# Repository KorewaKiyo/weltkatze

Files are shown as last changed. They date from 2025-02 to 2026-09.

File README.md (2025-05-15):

## A full hardware replacement for a small battery powered nightlight, which includes a bottom case, PCB + Zigbee microcontroller
Inspired by Blinkekatze

## Why?
It sounded like a fun challenge!

# More to come as the project progresses 
I've got boards but am waiting on some replacement components because I fried a couple MCUs while soldering :)

### Board view
animation

rendered with [kicad-render](https://github.com/linalinn/kicad-render)

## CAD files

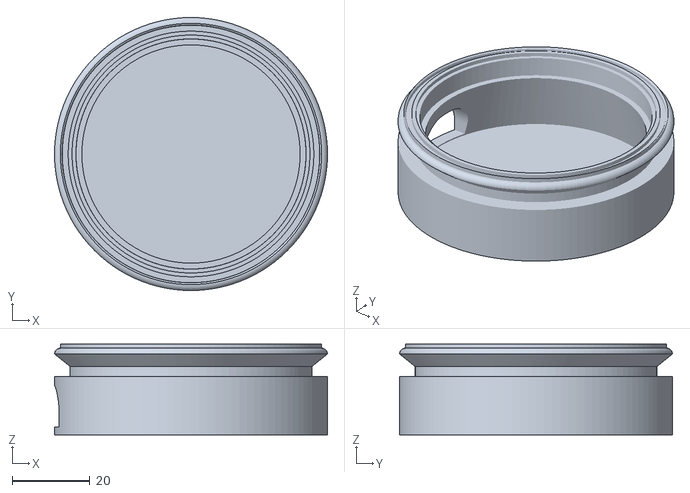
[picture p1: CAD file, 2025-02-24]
case/weltkatze_base.stl
70.0 x 70.0 x 23.2

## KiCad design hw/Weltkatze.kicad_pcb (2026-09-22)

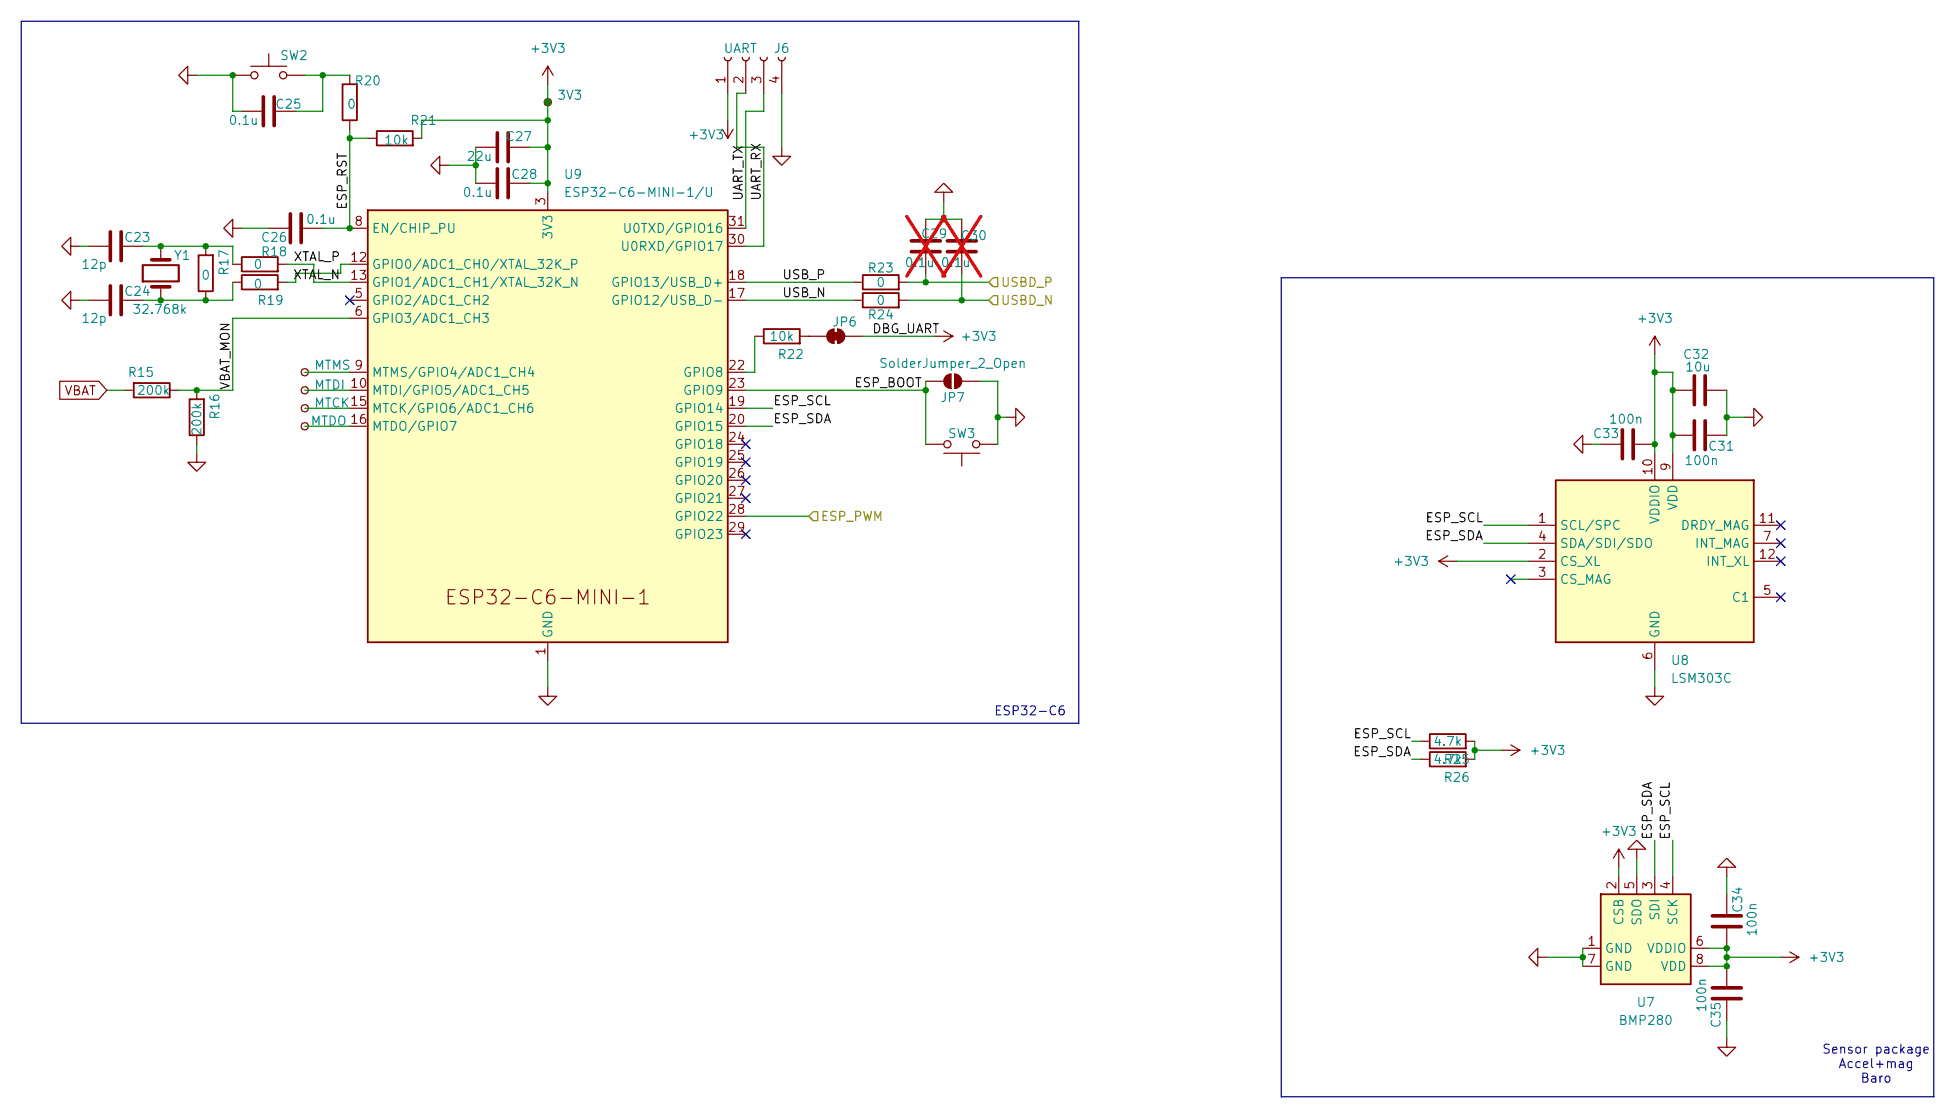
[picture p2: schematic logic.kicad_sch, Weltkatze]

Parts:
C23, C24: 12p; C_0402_1005Metric
C25, C26, C28: 0.1u; C_0402_1005Metric
C27: 22u; C_0805_2012Metric
C29, C30: 0.1u; C_0603_1608Metric; not fitted
C31, C33, C34, C35: 100n; C_0402_1005Metric
C32: 10u; C_0603_1608Metric
J6: UART; JST_ZH_B4B-ZR_1x04_P1.50mm_Vertical
JP6: DBG_UART; SolderJumper-2_P1.3mm_Bridged_Pad1.0x1.5mm
JP7: SolderJumper_2_Open; SolderJumper-2_P1.3mm_Open_TrianglePad1.0x1.5mm
R15, R16: 200k; R_0603_1608Metric
R17, R18, R19, R20, R23, R24: 0; R_0603_1608Metric
R21, R22: 10k; R_0603_1608Metric
R25, R26: 4.7k; R_0603_1608Metric
SW2, SW3: SW_Push; SW_SPST_CK_RS282G05A3
TP1: MTMS; TestPoint_Pad_D1.0mm
TP2: MTDI; TestPoint_Pad_D1.0mm
TP3: MTCK; TestPoint_Pad_D1.0mm
TP4: MTDO; TestPoint_Pad_D1.0mm
TP5: 3V3; TestPoint_Pad_D1.0mm
U7: BMP280; Bosch_LGA-8_2x2.5mm_P0.65mm_ClockwisePinNumbering
U8: LSM303C; LGA-12_2x2mm_P0.5mm
U9: ESP32-C6-MINI-1/U; ESP32-C6-MINI-1
Y1: 32.768k; Crystal_C26-LF_D2.1mm_L6.5mm_Horizontal

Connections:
+3V3: C27.2, C28.2, C31.1, C32.1, C33.1, C34.1, C35.1, J6.1, JP6.2 (B), R21.2, R25.2, R26.2, TP5.1, U7.2 (CSB), U7.6 (VDDIO), U7.8 (VDD), U8.2 (CS_XL), U8.9 (VDD), U8.10 (VDDIO), U9.3 (3V3); also elsewhere on the board
/LEDs/LED_DIN: U9.28 (GPIO22); also elsewhere on the board
/Logic/ESP_BOOT: JP7.1 (A), SW3.2, U9.23 (GPIO9)
/Logic/ESP_RST: C26.1, R20.1, R21.1, U9.8 (EN/CHIP_PU)
/Logic/ESP_SCL: R25.1, U7.4 (SCK), U8.1 (SCL/SPC), U9.19 (GPIO14)
/Logic/ESP_SDA: R26.1, U7.3 (SDI), U8.4 (SDA/SDI/SDO), U9.20 (GPIO15)
/Logic/UART_RX: J6.2, U9.30 (U0RXD/GPIO17)
/Logic/UART_TX: J6.3, U9.31 (U0TXD/GPIO16)
/Logic/USBD_N: C30.2, R24.2; also elsewhere on the board
/Logic/USBD_P: C29.2, R23.2; also elsewhere on the board
/Logic/USB_N: R24.1, U9.17 (GPIO12/USB_D-)
/Logic/USB_P: R23.1, U9.18 (GPIO13/USB_D+)
/Logic/VBAT_MON: R15.1, R16.2, U9.6 (GPIO3/ADC1_CH3)
/Logic/XTAL_N: R18.2, U9.13 (GPIO1/ADC1_CH1/XTAL_32K_N)
/Logic/XTAL_P: R19.2, U9.12 (GPIO0/ADC1_CH0/XTAL_32K_P)
GND: C23.1, C24.1, C25.1, C26.2, C27.1, C28.1, C29.1, C30.1, C31.2, C32.2, C33.2, C34.2, C35.2, J6.4, JP7.2 (B), R16.1, SW2.1, SW3.1, U7.1 (GND), U7.5 (SDO), U7.7 (GND), U8.6 (GND), U8.8 (GND), U9.1 (GND), U9.2 (GND), U9.11 (GND), U9.14 (GND), U9.36 (GND), U9.37 (GND), U9.38 (GND), U9.39 (GND), U9.40 (GND), U9.41 (GND), U9.42 (GND), U9.43 (GND), U9.44 (GND), U9.45 (GND), U9.46 (GND), U9.47 (GND), U9.48 (GND), U9.49 (GND), U9.50 (GND), U9.51 (GND), U9.52 (GND), U9.53 (GND); also elsewhere on the board
unnamed: C23.2, R17.2, R18.1, Y1.2
unnamed: C24.2, R17.1, R19.1, Y1.1
unnamed: C25.2, R20.2, SW2.2
unnamed: JP6.1 (A), R22.2
unnamed: R22.1, U9.22 (GPIO8)
unnamed: TP3.1, U9.15 (MTCK/GPIO6/ADC1_CH6)
unnamed: TP2.1, U9.10 (MTDI/GPIO5/ADC1_CH5)
unnamed: TP4.1, U9.16 (MTDO/GPIO7)
unnamed: TP1.1, U9.9 (MTMS/GPIO4/ADC1_CH4)
VBAT: R15.2; also elsewhere on the board

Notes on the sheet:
Sensor package Accel+mag Baro
ESP32-C6

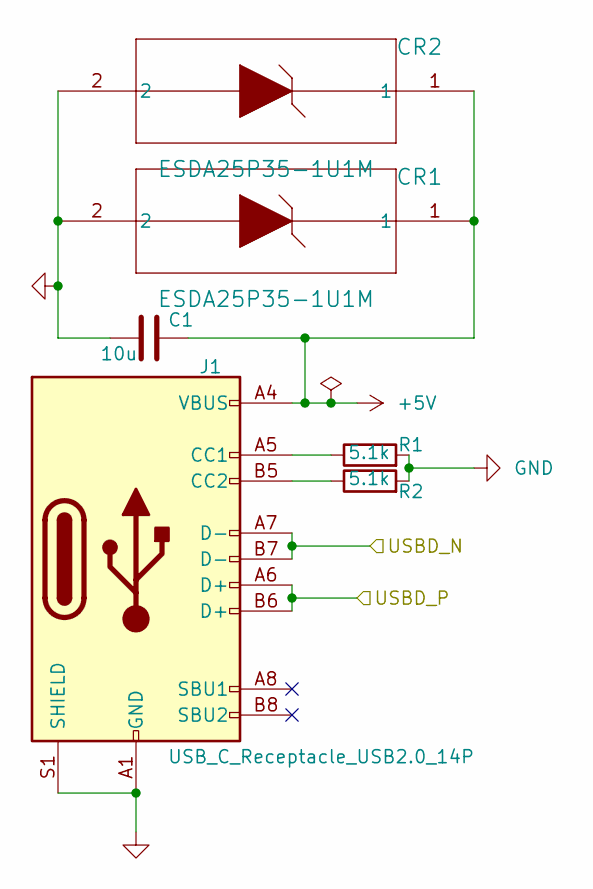
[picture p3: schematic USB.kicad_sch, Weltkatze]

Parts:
C1: 10u; C_0603_1608Metric
CR1, CR2: ESDA25P35-1U1M; QFN1610_STM-M
J1: USB_C_Receptacle_USB2.0_14P; USB_C_Receptacle_HCTL_HC-TYPE-C-16P-01A
R1, R2: 5.1k; R_0603_1608Metric

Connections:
+5V: C1.1, CR1.1, CR2.1, J1.A4 (VBUS), J1.A9 (VBUS), J1.B4 (VBUS), J1.B9 (VBUS); also elsewhere on the board
/Logic/USBD_N: J1.A7 (D-), J1.B7 (D-); also elsewhere on the board
/Logic/USBD_P: J1.A6 (D+), J1.B6 (D+); also elsewhere on the board
GND: C1.2, CR1.2, CR2.2, J1.A1 (GND), J1.A12 (GND), J1.B1 (GND), J1.B12 (GND), J1.S1 (SHIELD), R1.2, R2.2; also elsewhere on the board
unnamed: J1.A5 (CC1), R1.1
unnamed: J1.B5 (CC2), R2.1

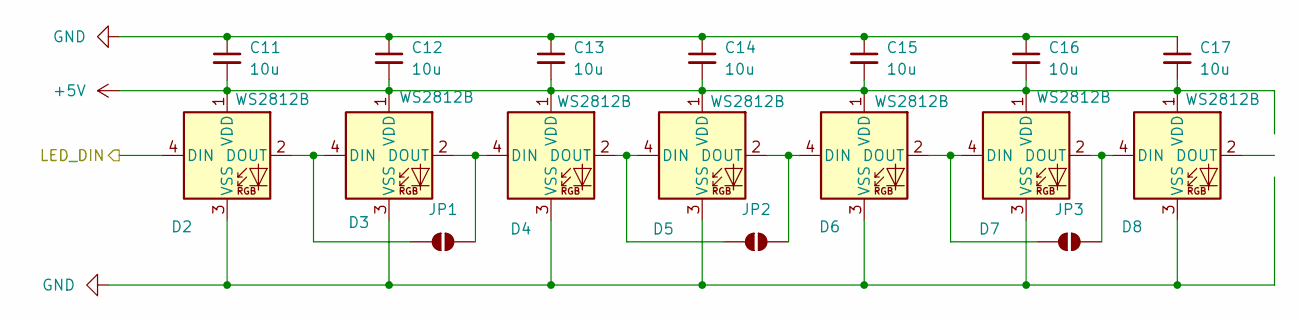
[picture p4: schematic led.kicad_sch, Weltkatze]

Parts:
C11, C12, C13, C14, C15, C16, C17: 10u; C_0603_1608Metric
D2, D3, D4, D5, D6, D7, D8: WS2812B; LED_WS2812B_PLCC4_5.0x5.0mm_P3.2mm
JP1, JP2, JP3: SolderJumper_2_Open; SolderJumper-2_P1.3mm_Open_TrianglePad1.0x1.5mm

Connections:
+5V: C11.2, C12.2, C13.2, C14.2, C15.2, C16.2, C17.2, D2.1 (VDD), D3.1 (VDD), D4.1 (VDD), D5.1 (VDD), D6.1 (VDD), D7.1 (VDD), D8.1 (VDD); also elsewhere on the board
/LEDs/LED_DIN: D2.4 (DIN); also elsewhere on the board
GND: C11.1, C12.1, C13.1, C14.1, C15.1, C16.1, C17.1, D2.3 (VSS), D3.3 (VSS), D4.3 (VSS), D5.3 (VSS), D6.3 (VSS), D7.3 (VSS), D8.3 (VSS); also elsewhere on the board
unnamed: D2.2 (DOUT), D3.4 (DIN), JP1.1 (A)
unnamed: D3.2 (DOUT), D4.4 (DIN), JP1.2 (B)
unnamed: D4.2 (DOUT), D5.4 (DIN), JP2.1 (A)
unnamed: D5.2 (DOUT), D6.4 (DIN), JP2.2 (B)
unnamed: D6.2 (DOUT), D7.4 (DIN), JP3.1 (A)
unnamed: D7.2 (DOUT), D8.4 (DIN), JP3.2 (B)

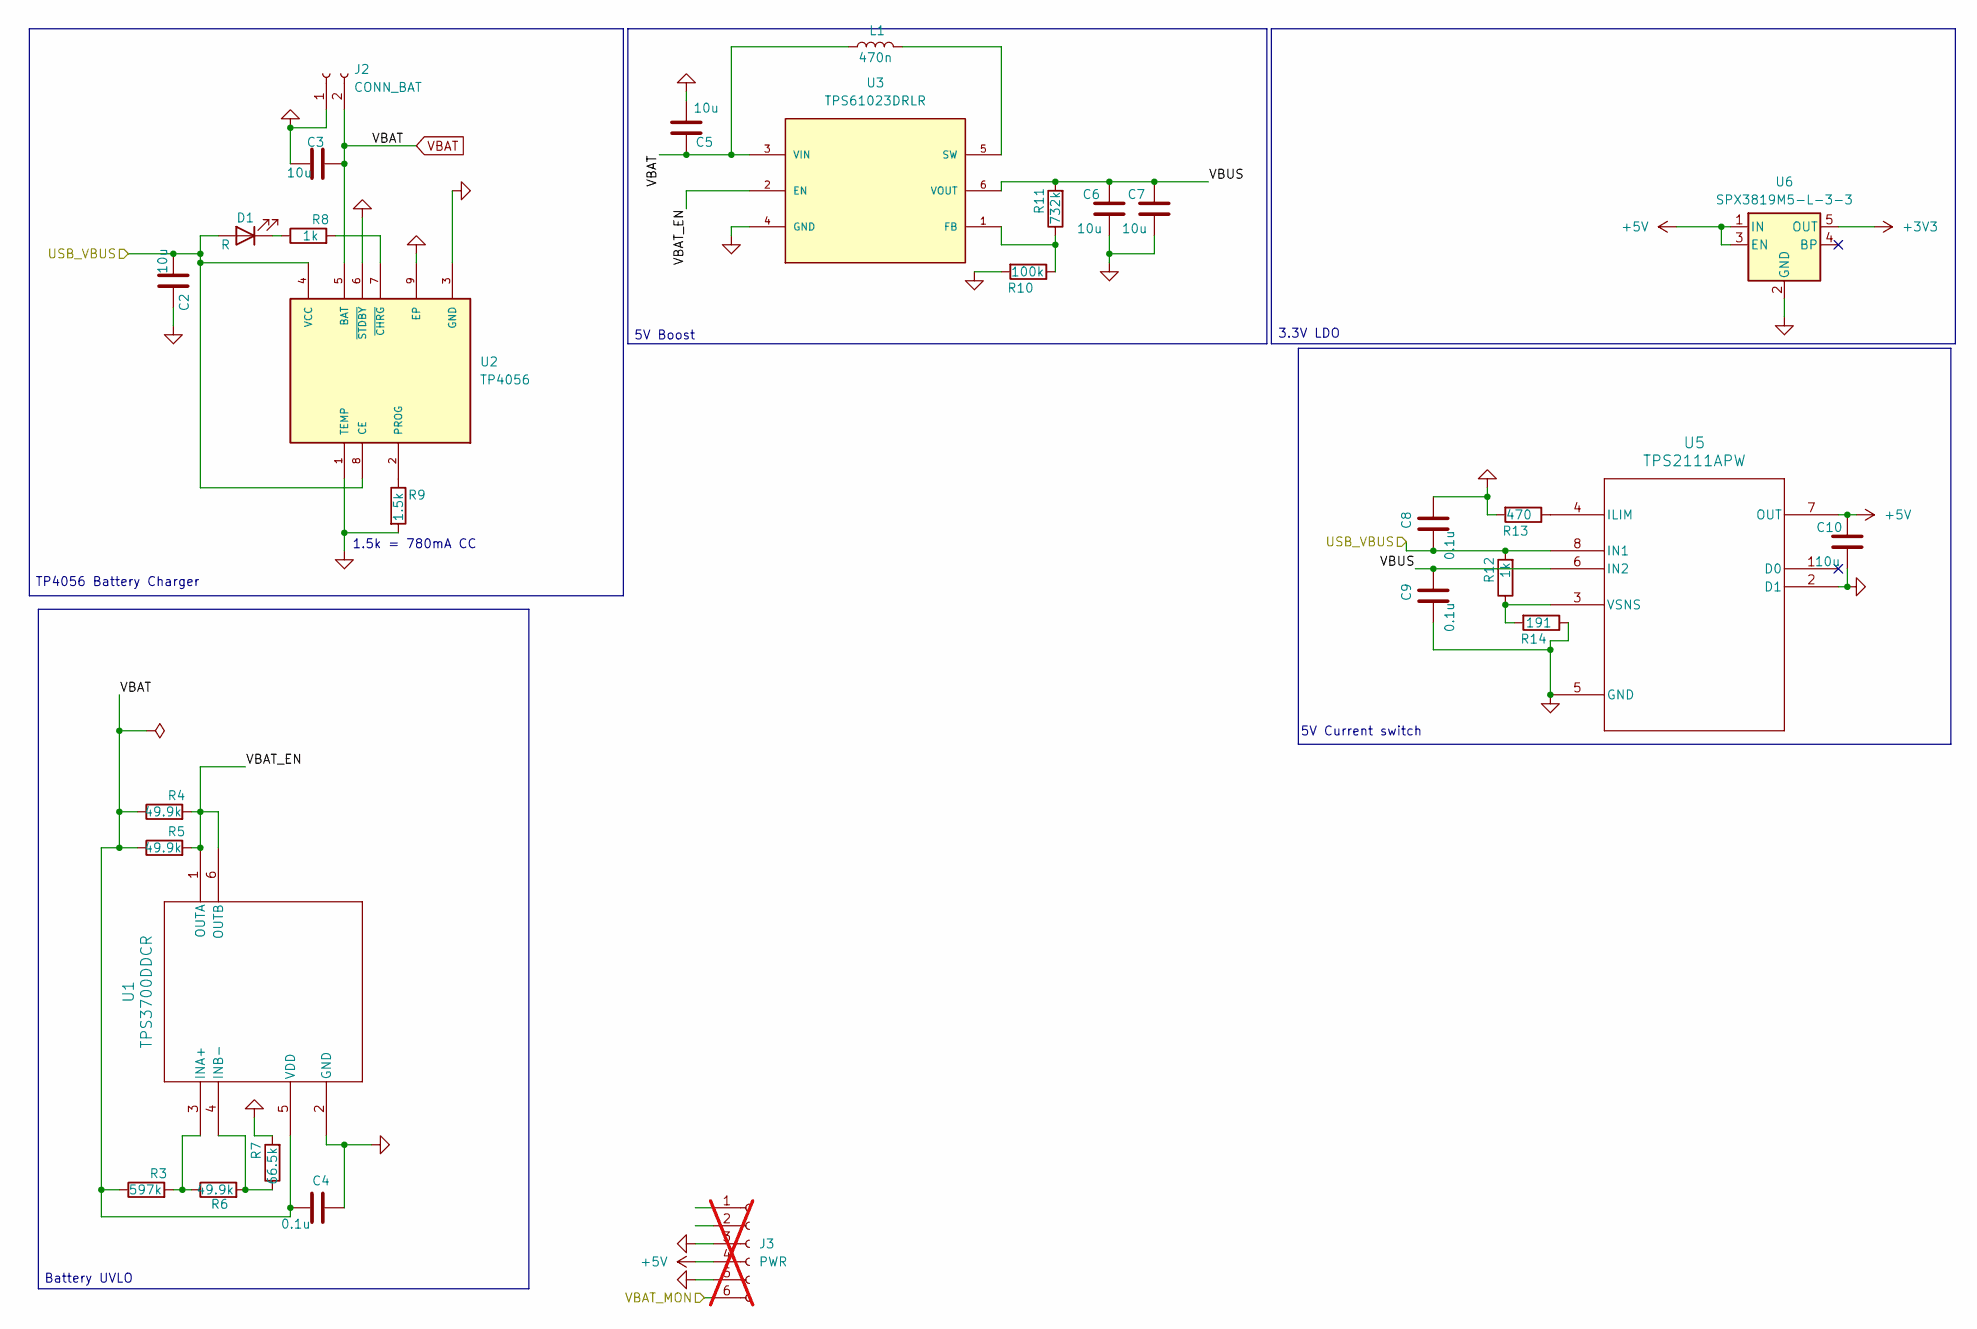
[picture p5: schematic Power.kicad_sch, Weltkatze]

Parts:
C2, C3, C5, C6, C7, C10: 10u; C_0603_1608Metric
C4, C8, C9: 0.1u; C_0402_1005Metric
D1: R; LED_0603_1608Metric
J2: CONN_BAT; JST_XH_B2B-XH-A_1x02_P2.50mm_Vertical
J3: PWR; JST_ZH_B6B-ZR_1x06_P1.50mm_Vertical; not fitted
L1: 470n; L_0805_2012Metric
R3: 597k; R_0603_1608Metric
R4, R5, R6: 49.9k; R_0603_1608Metric
R7: 66.5k; R_0603_1608Metric
R8, R12: 1k; R_0603_1608Metric
R9: 1.5k; R_0603_1608Metric
R10: 100k; R_0603_1608Metric
R11: 732k; R_0603_1608Metric
R13: 470; R_0603_1608Metric
R14: 191; R_0603_1608Metric
U1: TPS3700DDCR; DDC6_TEX-M
U2: TP4056; SOP127P600X175-9N
U3: TPS61023DRLR; DRL0006A; MANUFACTURER_PART_NUMBER TPS61023DRLR
U5: TPS2111APW; PW8
U6: SPX3819M5-L-3-3; SOT-23-5

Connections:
+3V3: U6.5 (OUT); also elsewhere on the board
+5V: C10.1, J3.4, U5.7 (OUT), U6.1 (IN), U6.3 (EN); also elsewhere on the board
/Power/USB_VBUS: C2.1, C8.1, D1.2 (A), R12.2, U2.4 (VCC), U2.8 (CE), U5.8 (IN1)
/Power/VBAT_EN: R4.2, R5.2, U1.1 (OUTA), U1.6 (OUTB), U3.2 (EN)
/Power/VBUS: C6.1, C7.1, C9.2, R11.2, U3.6 (VOUT), U5.6 (IN2)
GND: C2.2, C3.2, C4.2, C5.2, C6.2, C7.2, C8.2, C9.1, C10.2, J2.1, J3.3, J3.5, R7.2, R9.2, R10.2, R13.2, R14.1, U1.2 (GND), U2.1 (TEMP), U2.3 (GND), U2.6 (~STDBY), U2.9 (EP), U3.4 (GND), U5.2 (D1), U5.5 (GND), U6.2 (GND); also elsewhere on the board
unnamed: D1.1 (K), R8.1
unnamed: R3.2, R6.1, U1.3 (INA+)
unnamed: R6.2, R7.1, U1.4 (INB-)
unnamed: R9.1, U2.2 (PROG)
unnamed: R8.2, U2.7 (~CHRG)
unnamed: R10.1, R11.1, U3.1 (FB)
unnamed: L1.2, U3.5 (SW)
unnamed: R13.1, U5.4 (ILIM)
unnamed: R12.1, R14.2, U5.3 (VSNS)
VBAT: C3.1, C4.1, C5.1, J2.2, L1.1, R3.1, R4.1, R5.1, U1.5 (VDD), U2.5 (BAT), U3.3 (VIN); also elsewhere on the board

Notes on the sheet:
5V Boost
TP4056 Battery Charger
Battery UVLO
3.3V LDO
1.5k = 780mA CC
5V Current switch

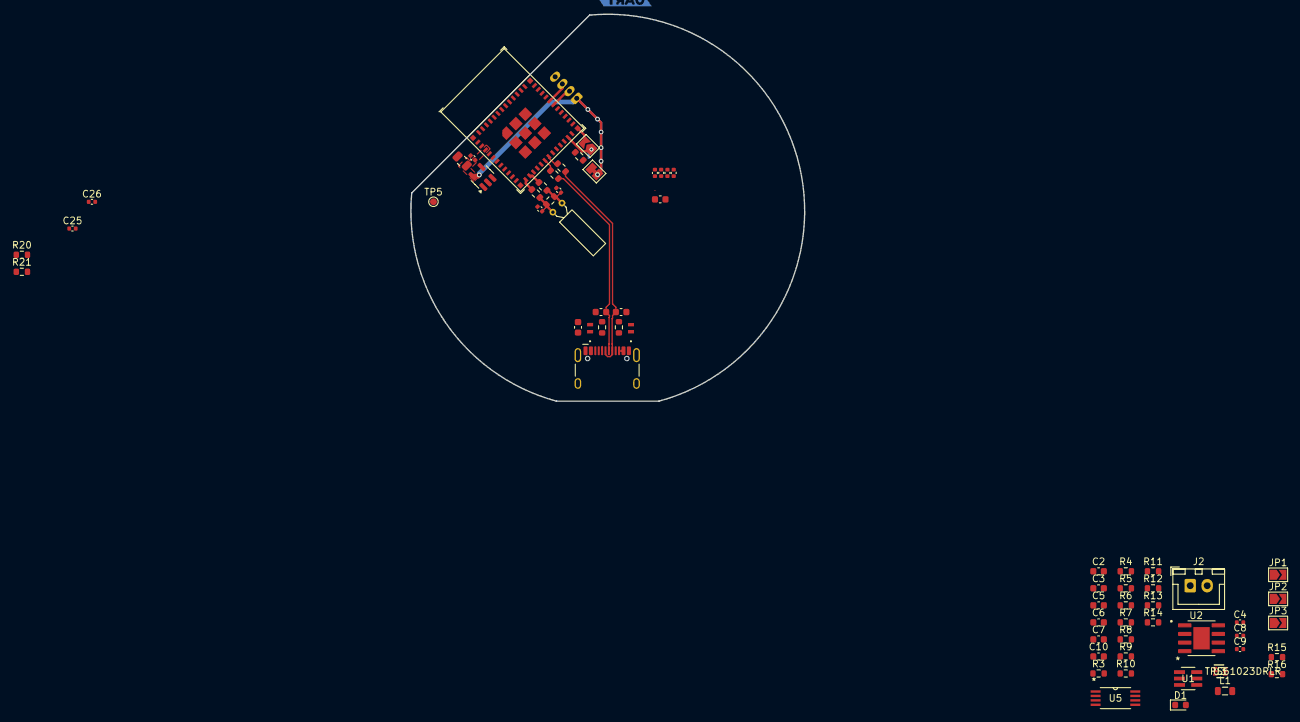
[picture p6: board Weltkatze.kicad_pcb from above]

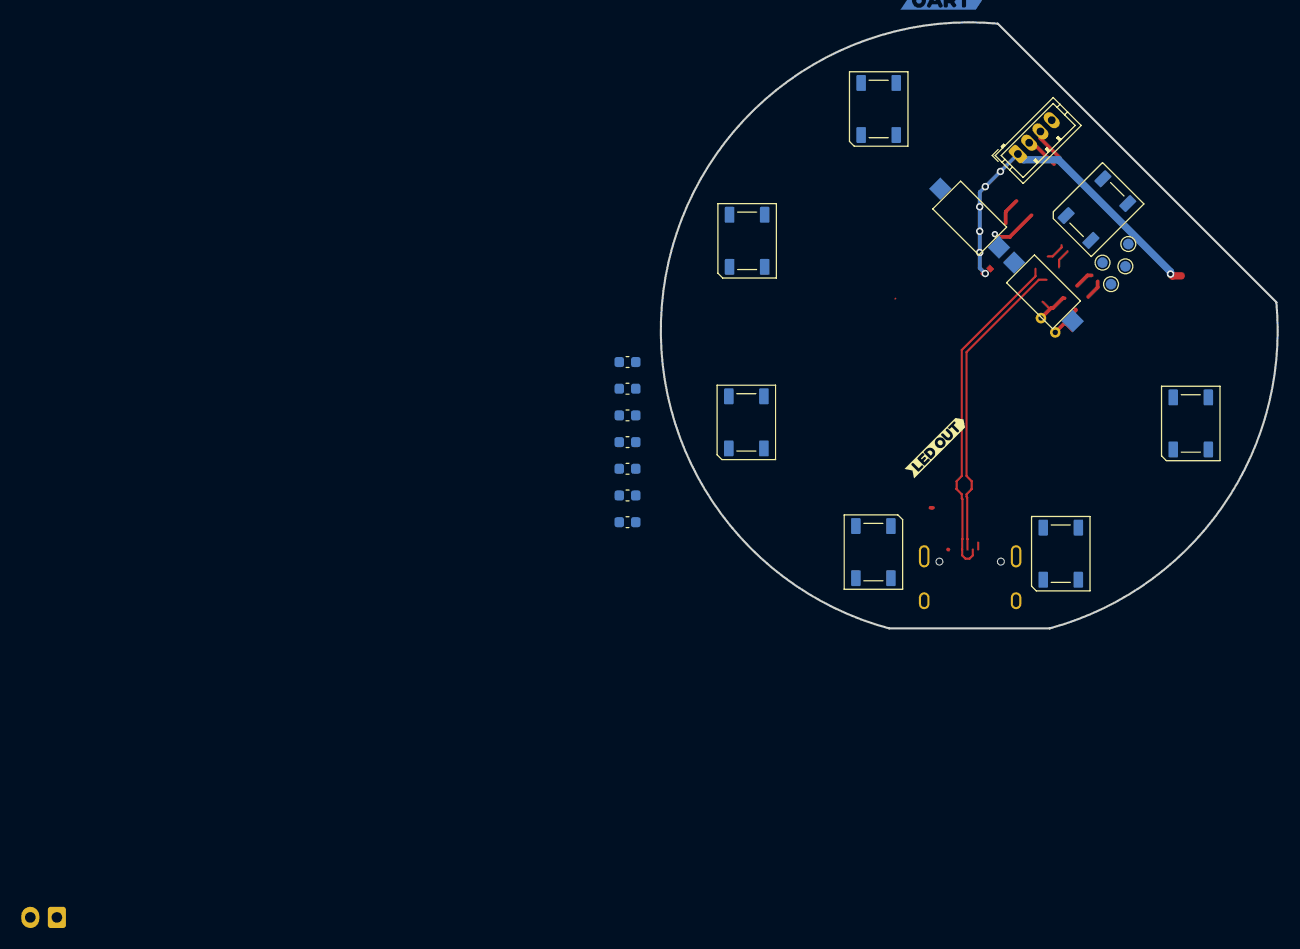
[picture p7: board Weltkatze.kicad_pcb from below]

Board: 2 copper layers, 58.0 x 57.0 mm, 89 parts (23 on the bottom side), 45 nets.

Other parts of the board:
kibuzzard-67CB17AB: G***; kibuzzard-67CB17AB
kibuzzard-698E3F4A: G***; kibuzzard-698E3F4A

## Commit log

2024-10-08 Start working on ESP32 implementation
    This commit starts working on getting a working ESP32 implemented
    Need to implement power stages.
    [Weltkatze.kicad_pcb, Weltkatze.kicad_sch]
2025-02-21 Start actual work
    I've settled on the ESP32C6, as the SEEED Xiao board based on this chipset works great. So I've started work on implementing that
    [Power.kicad_sch, USB.kicad_sch, Weltkatze.kicad_pcb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]
2025-02-24 Replace case, start on Power stages
    I've replaced the case STL with one that's better in every way, it prints faster, doesn't need supports, and the holder for the diffuser is better,
    I may still tweak the design but I'm happy with it for now.
    [Power.kicad_sch, logic.kicad_sch, weltkatze_base.stl]
2025-02-24 Finish power stage, work on other stages
    Power stage should be finalised, I've updated LED stage to include a solder jumper, to allow up to half of the LEDs to be removed in the case of power/cost savings
    [Power.kicad_sch, Weltkatze.kicad_sch, led.kicad_sch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]
2025-02-25 Work on footprinting and PCB
    [Power.kicad_sch, USB.kicad_sch, Weltkatze.kicad_pcb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]
2025-02-25 Footprinting, begin layout
    I've assigned all the footprints except a few, so I've started on layout.
    [Power.kicad_sch, USB.kicad_sch, Weltkatze.kicad_pcb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]
2025-03-05 Rest of the owl
    Finish major layout, minor tweaks can be made
    E.g. rotating the LEDs so they look pretty
    Still need to make it so the inner PCB is manufacturable
    [Power.kicad_sch, USB.kicad_sch, Weltkatze.kicad_sch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]
2025-03-05 I'm actually really stupid.
    I made the board sized for a RADIUS of 60mm
    and not a DIAMETER of 60mm like the damn fusion model.
    [led.kicad_sch]
2025-03-10 V1 REV1 Final!
    I consider this design finished, as such I've submitted it to JLCPCB
    I converted to a 6L pcb because its cheaper, in.3 and in.4 have no copper
    [Power.kicad_sch, USB.kicad_sch, Weltkatze.kicad_pcb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]
2025-03-12 rev1.5
    Update to use 6 layers, inc one for 5V
    Can possibly eliminate all front copper but i like how it looks
    [Weltkatze.kicad_pcb]
2025-04-29 Minor reroute
    Minor reroute of traces, utilises all 6 layers effectively now.
    Also reduces some issues with USB going through multiple layers unnecessarily
    [Power.kicad_sch, Weltkatze.kicad_pcb, logic.kicad_sch]
2025-12-16 Update to kicad v9
    [Power.kicad_sch, USB.kicad_sch, Weltkatze.kicad_pcb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]
2026-02-10 Redesign work
    I'm going towards a single-sided minimum viable design, so that I only need to place and hotplate one side to verify function, before adding things like battery and USB by hand.
    [Weltkatze.kicad_pcb, led.kicad_sch, logic.kicad_sch]
2026-09-22 USB fix and schematic cleanup (April work)
    Add CR2 ESDA25P35 on the USB lines and tie VBUS straight to +5V, drop
    the ESP_PWR header J7, JP9 and the VBAT_MON divider, add R25 4.7k and
    wire the LSM303C I2C, remove the external LED output (D9, J4, C18).
    [USB.kicad_sch, Weltkatze.kicad_pcb, Weltkatze.kicad_sch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]

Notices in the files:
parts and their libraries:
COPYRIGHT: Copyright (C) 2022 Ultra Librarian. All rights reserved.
